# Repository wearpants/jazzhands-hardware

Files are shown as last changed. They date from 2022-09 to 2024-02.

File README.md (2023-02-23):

# Jazz Hands PCBs

A small multi-PCB handheld keyboard for chording style input.

## Main

The main "brains" PCB, which accepts a nice!nano controller.
It exposes connection points with Molex Pico EZMate connectors for 5 `key` PCBs, and a 3-pin Molex Pico EZMate connector for use with the `power-reset` daughterboard PCB.
An untested IMU is also on the main PCB, for future use.

## Key

A small single key PCB with Molex Pico EZMate connector, Kailh hotswap socket, and mounting holes for possible assembly. One mounting hole "wing" is breakaway, as needed.

## Power/Reset

A small daughterboard PCB that contains a reset button and power switch, allowing those two components to be placed elsewhere in a case

# Firmware

See the `wearpants/jazzhands-zmk-config` repo for firmware for the main PCB with ZMK.

# Custom Modifications

It's possible to hack the current `main` PCB to also support a digital hall-effect sensor like the [DRV5023](https://www.ti.com/product/DRV5023) for use in a handheld "switchless design" using magnets only for activation in a glove.

# Production

All three PCBs can be produced by grabbing the generated files from the Actions tab and uploading to JLC, including partial assembly for the `main` PCB using JLC's PCBA service.

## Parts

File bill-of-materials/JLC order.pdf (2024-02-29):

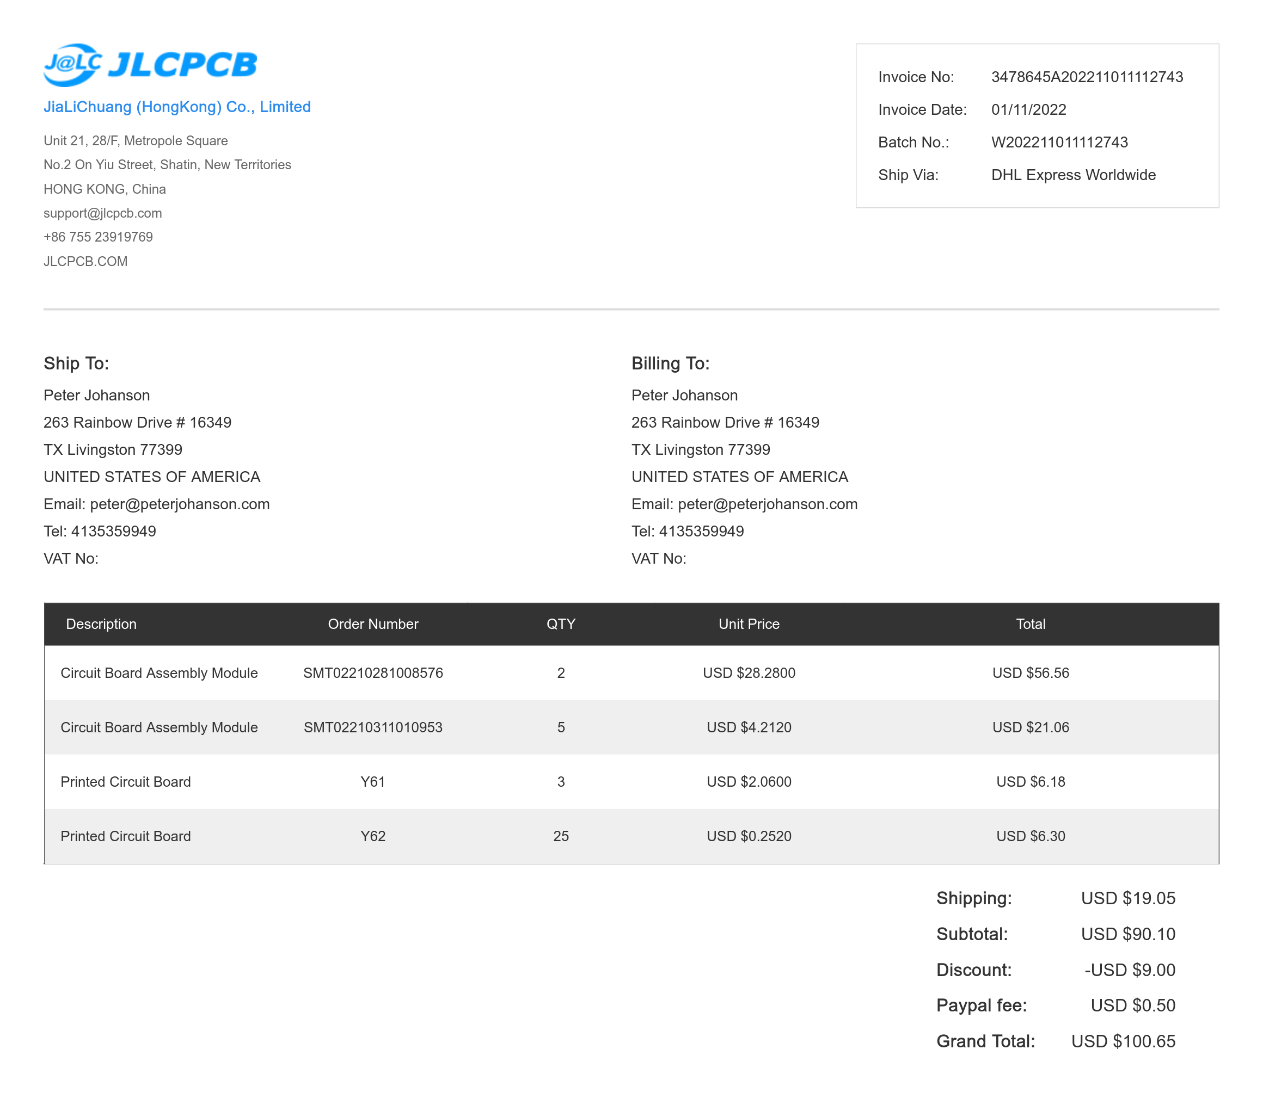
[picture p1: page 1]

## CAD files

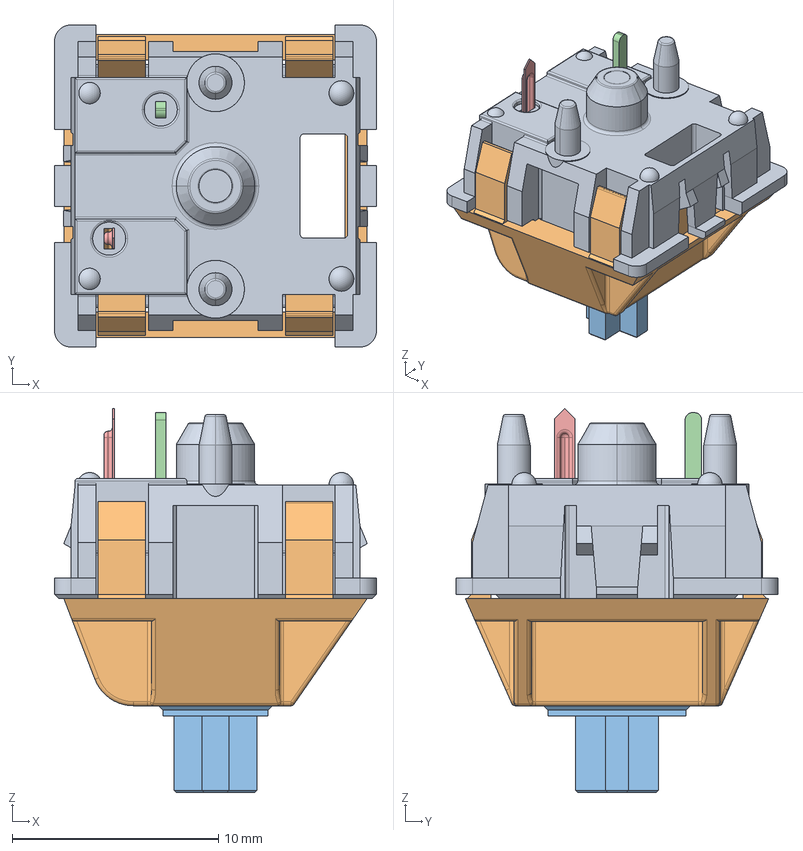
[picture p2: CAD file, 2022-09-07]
key/3d-models/asm_mx_asm_PCB.stp
15.6 x 15.6 x 18.6 mm
MX_DOWN
MX_UP
UP_MX
MX_PIN
MX_SPRING
MX_CLICK

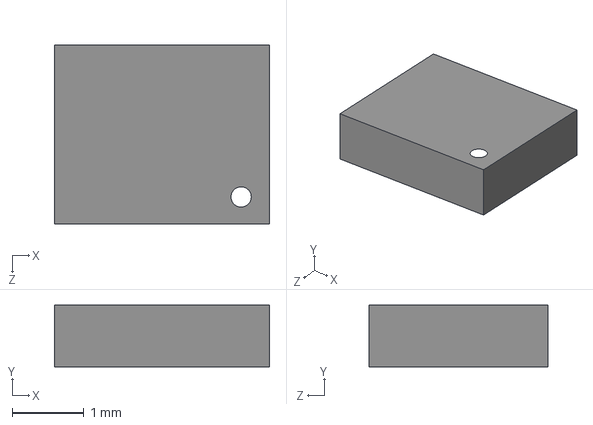
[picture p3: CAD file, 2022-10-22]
main/3d-models/LSM6DSOXTR.step
3.00 x 0.86 x 2.50 mm

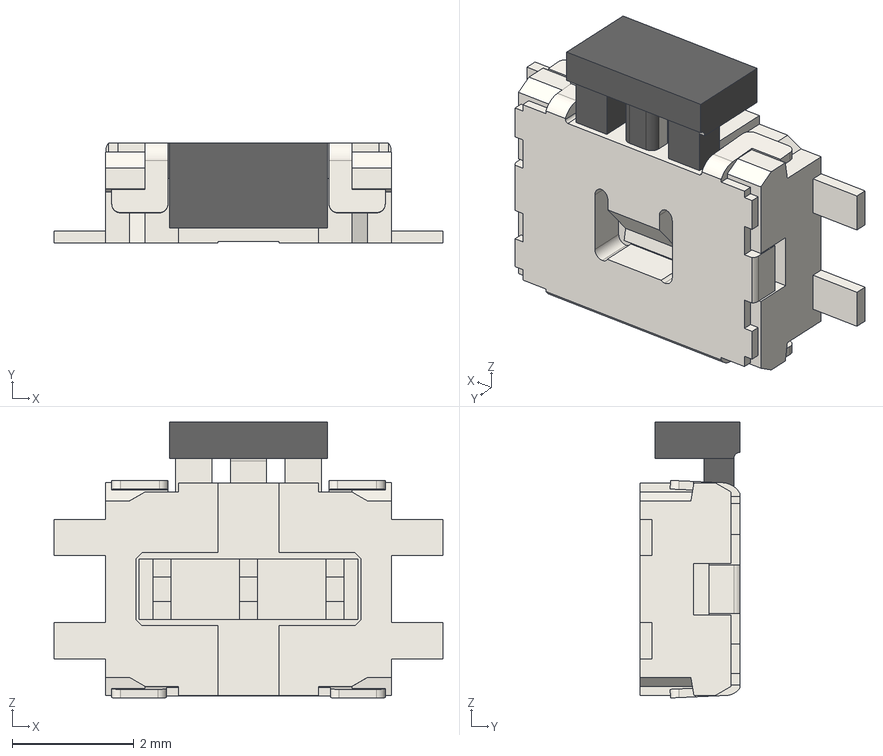
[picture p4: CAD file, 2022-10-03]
power-reset/3d-models/EVQPU-JA-02K.STEP
6.40 x 1.65 x 4.54 mm

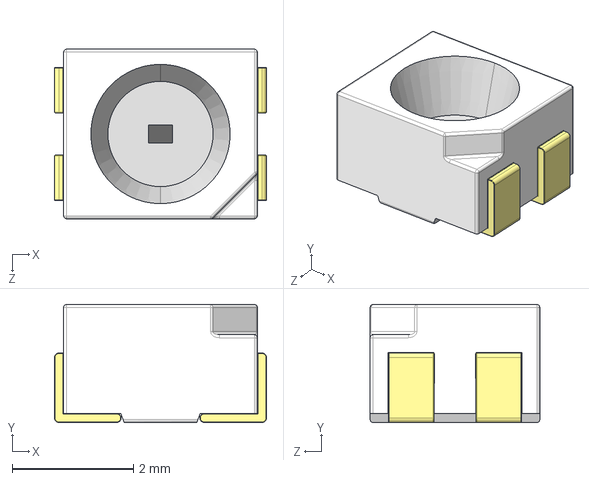
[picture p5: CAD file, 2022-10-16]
main/3d-models/Osram_Led_PLCC4-1.step
3.50 x 1.95 x 2.80 mm

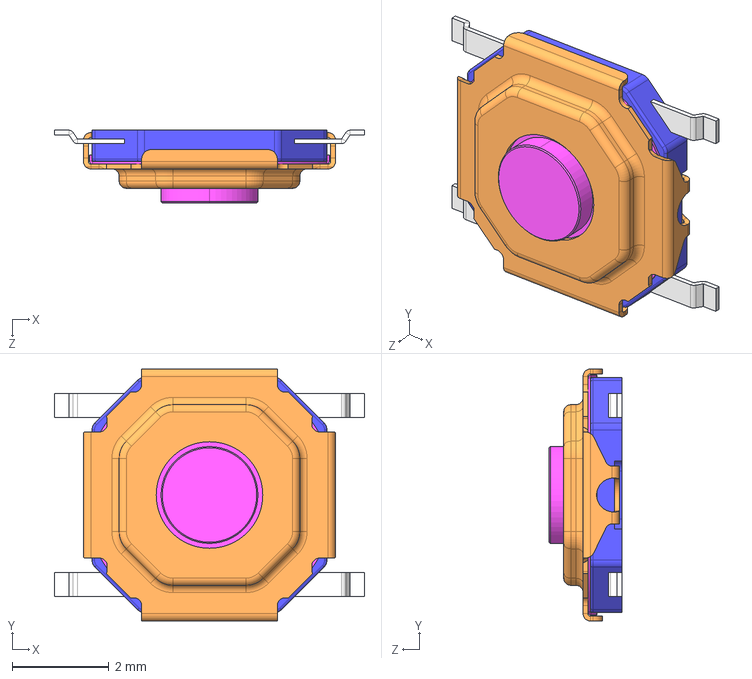
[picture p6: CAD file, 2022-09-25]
main/3d-models/SKQGAF.STEP
6.40 x 5.20 x 1.50 mm

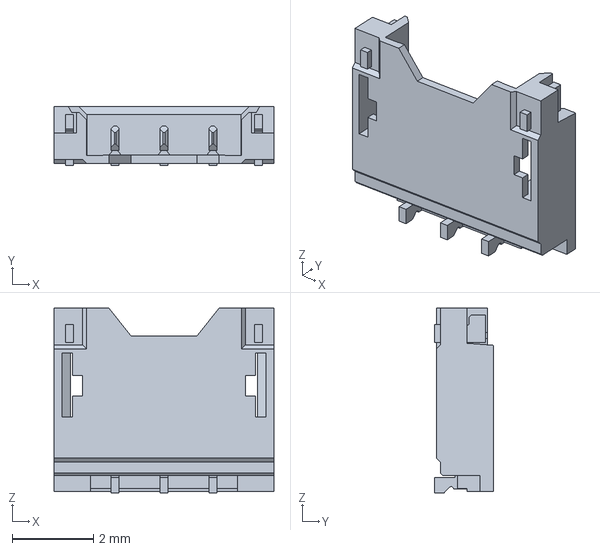
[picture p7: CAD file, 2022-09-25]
power-reset/3d-models/781710003.stp
5.40 x 1.45 x 4.53 mm

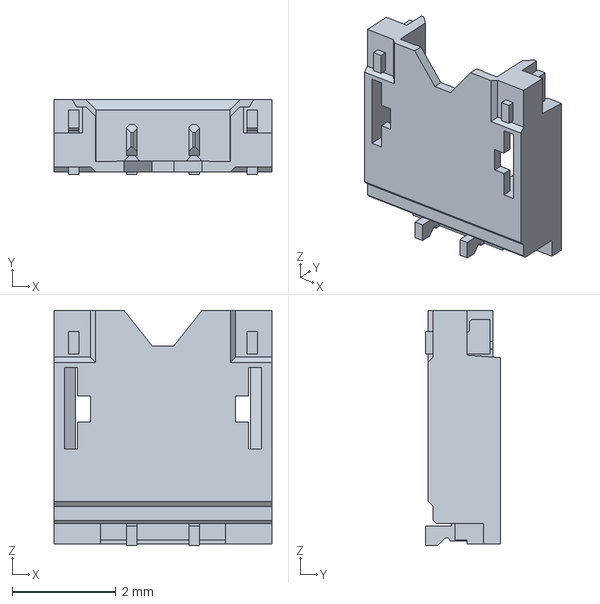
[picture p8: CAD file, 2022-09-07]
main/3d-models/781710002.stp
4.20 x 1.45 x 4.53 mm

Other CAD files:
key/key-sketch.FCStd

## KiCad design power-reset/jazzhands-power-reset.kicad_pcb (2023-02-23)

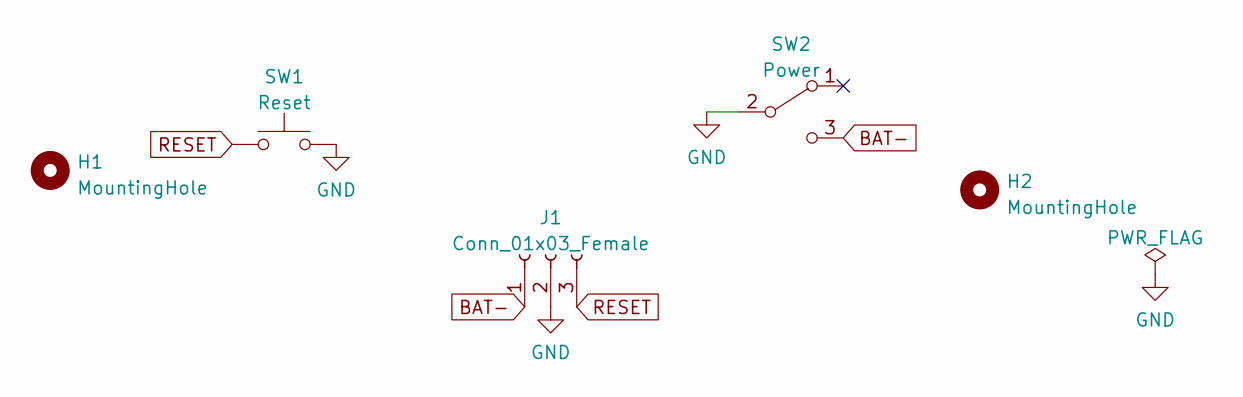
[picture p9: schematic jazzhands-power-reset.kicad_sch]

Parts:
H1, H2: MountingHole; MountingHole_3.2mm_M3_Pad
J1: Conn_01x03_Female; Molex_Pico-EZmate_78171-0003_1x03-1MP_P1.20mm_Vertical
SW1: Reset; Panasonic_EVQPUL_EVQPUC; LCSC Part Number C79174
SW2: Power; SW_SPDT_PCM12; LCSC Part Number C221841

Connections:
BAT-: J1.1, SW2.3 (C)
GND: J1.2, SW1.1, SW2.2 (B)
RESET: J1.3, SW1.2

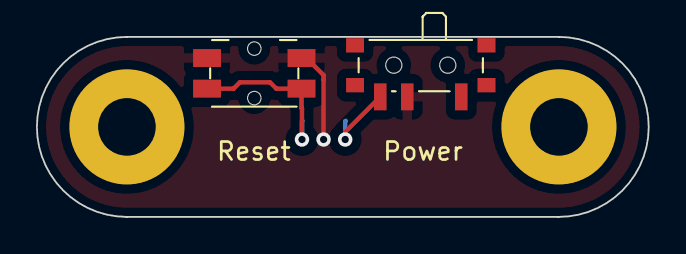
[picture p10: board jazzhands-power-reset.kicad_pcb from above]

Board: 2 copper layers, 34.0 x 10.0 mm, 5 parts (1 on the bottom side), 3 nets.

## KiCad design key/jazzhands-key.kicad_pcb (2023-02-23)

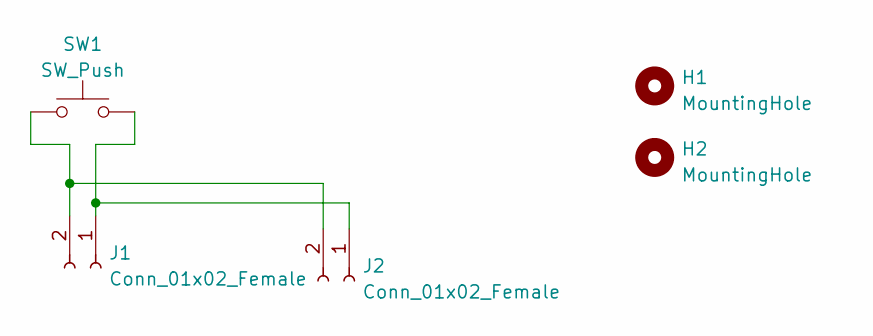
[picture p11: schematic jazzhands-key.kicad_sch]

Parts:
H1, H2: MountingHole; MountingHole_2.2mm_M2_Pad_TopBottom
J1, J2: Conn_01x02_Female; Molex_Pico-EZmate_78171-0002_1x02-1MP_P1.20mm_Vertical
SW1: SW_Push; MXOnly-1U-Hotswap-Antishear

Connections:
unnamed: J1.1, J2.1, SW1.2
unnamed: J1.2, J2.2, SW1.1

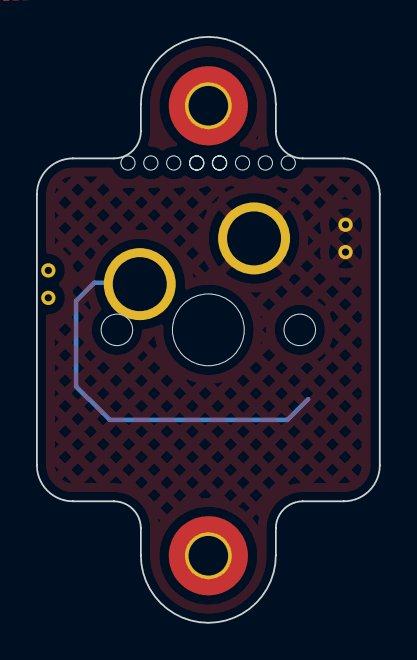
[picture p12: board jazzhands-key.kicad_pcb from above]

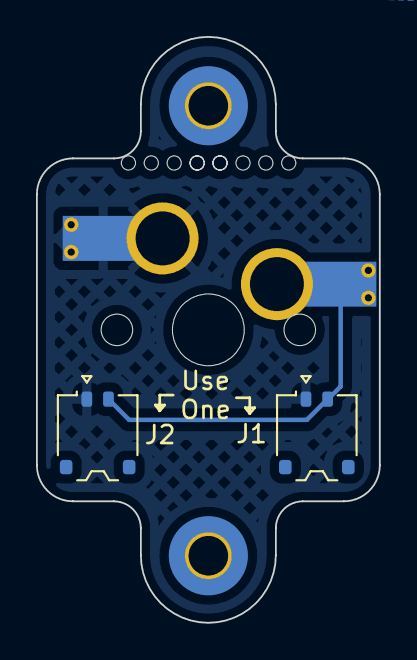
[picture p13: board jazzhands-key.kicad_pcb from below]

Board: 2 copper layers, 19.1 x 32.6 mm, 5 parts (2 on the bottom side), 2 nets.

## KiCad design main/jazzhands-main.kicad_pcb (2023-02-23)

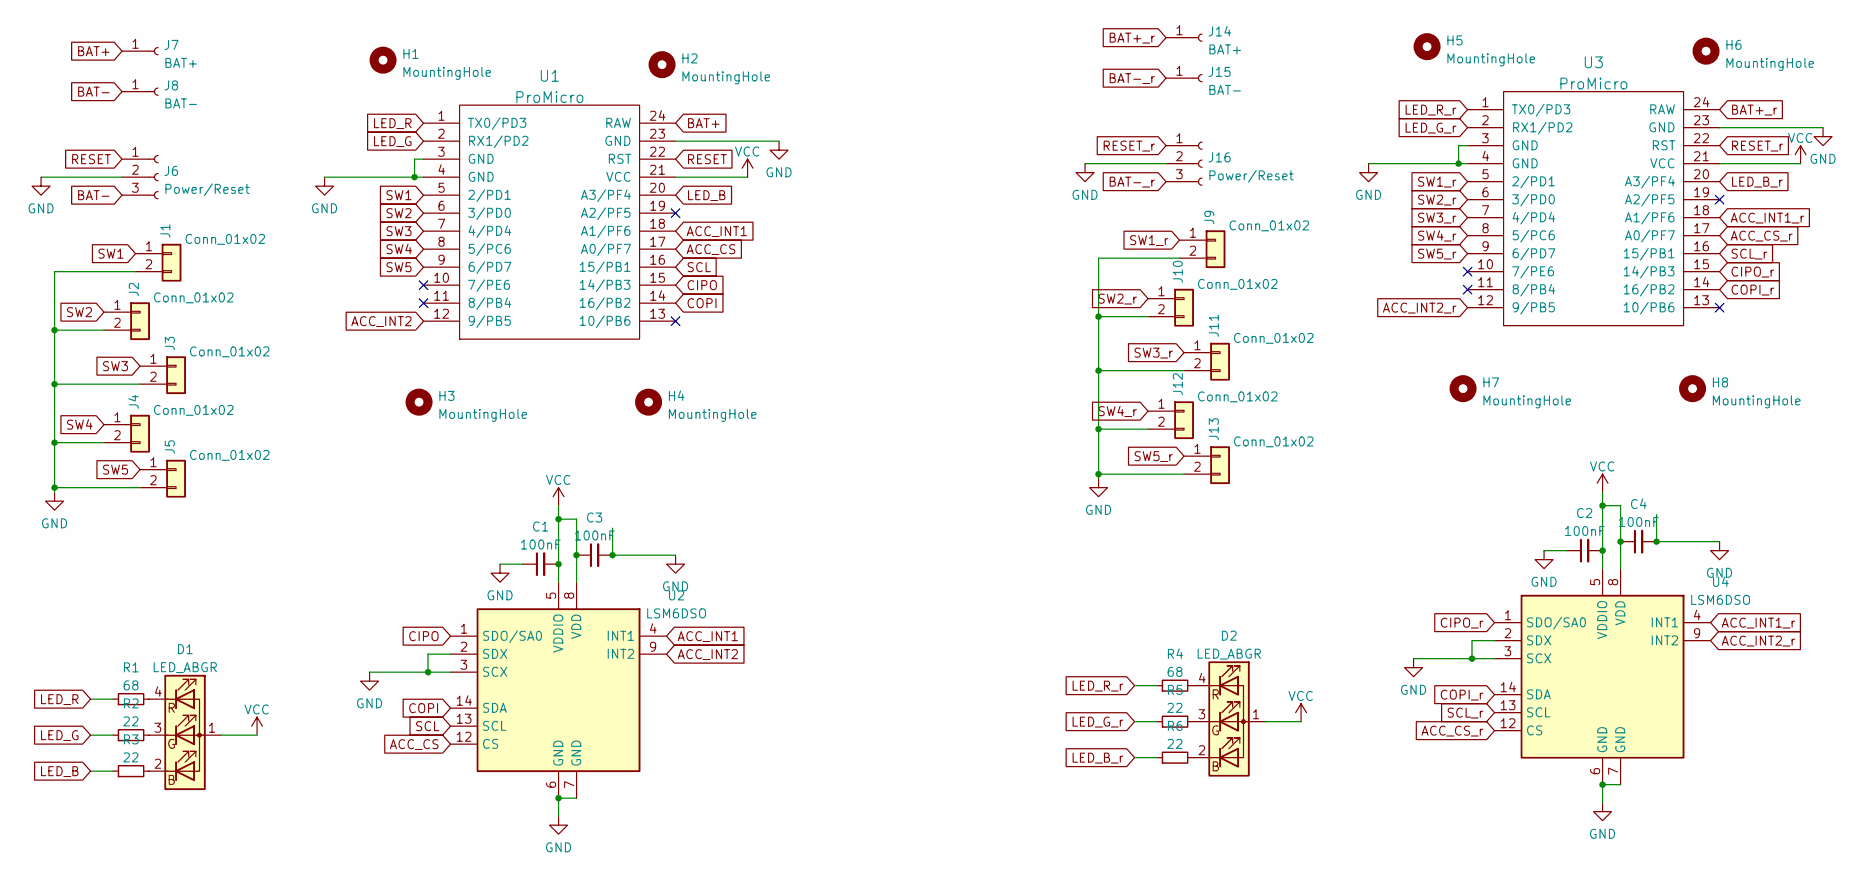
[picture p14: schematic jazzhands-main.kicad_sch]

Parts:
C1, C2, C3, C4: 100nF; C_0603_1608Metric; LCSC Part Number C14663
D1, D2: LED_ABGR; LED_RGB_Wuerth-PLCC4_3.2x2.8mm_150141M173100; LCSC Part Number C409779
H1, H2, H3, H4, H5, H6, H7, H8: MountingHole; MountingHole_2.2mm_M2_Pad
J1, J2, J3, J4, J5, J9, J10, J11, J12, J13: Conn_01x02; Molex_Pico-EZmate_78171-0002_1x02-1MP_P1.20mm_Vertical
J6, J16: Power/Reset; Molex_Pico-EZmate_78171-0003_1x03-1MP_P1.20mm_Vertical
J7, J14: BAT+; PinSocket_1x01_P2.54mm_Vertical
J8, J15: BAT-; PinSocket_1x01_P2.54mm_Vertical
R1, R4: 68; R_0603_1608Metric; LCSC Part Number C27592
R2, R3, R5, R6: 22; R_0603_1608Metric; LCSC Part Number C23345
U1, U3: ProMicro; ArduinoProMicro
U2, U4: LSM6DSO; PQFN50P250X300X86-14N; LCSC Part Number C2655100

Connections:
ACC_CS: U1.17 (A0/PF7), U2.12 (CS)
ACC_CS_r: U3.17 (A0/PF7), U4.12 (CS)
ACC_INT1: U1.18 (A1/PF6), U2.4 (INT1)
ACC_INT1_r: U3.18 (A1/PF6), U4.4 (INT1)
ACC_INT2: U1.12 (9/PB5), U2.9 (INT2)
ACC_INT2_r: U3.12 (9/PB5), U4.9 (INT2)
BAT+: J7.1, U1.24 (RAW)
BAT+_r: J14.1, U3.24 (RAW)
BAT-: J6.3, J8.1
BAT-_r: J15.1, J16.3
CIPO: U1.15 (14/PB3), U2.1 (SDO/SA0)
CIPO_r: U3.15 (14/PB3), U4.1 (SDO/SA0)
COPI: U1.14 (16/PB2), U2.14 (SDA)
COPI_r: U3.14 (16/PB2), U4.14 (SDA)
LED_B: R3.1, U1.20 (A3/PF4)
LED_B_r: R6.1, U3.20 (A3/PF4)
LED_G: R2.1, U1.2 (RX1/PD2)
LED_G_r: R5.1, U3.2 (RX1/PD2)
LED_R: R1.1, U1.1 (TX0/PD3)
LED_R_r: R4.1, U3.1 (TX0/PD3)
unnamed: D1.2 (BK), R3.2
unnamed: D1.3 (GK), R2.2
unnamed: D1.4 (RK), R1.2
unnamed: D2.2 (BK), R6.2
unnamed: D2.3 (GK), R5.2
unnamed: D2.4 (RK), R4.2
RESET: J6.1, U1.22 (RST)
RESET_r: J16.1, U3.22 (RST)
SCL: U1.16 (15/PB1), U2.13 (SCL)
SCL_r: U3.16 (15/PB1), U4.13 (SCL)
SW1: J1.1, U1.5 (2/PD1)
SW1_r: J9.1, U3.5 (2/PD1)
SW2: J2.1, U1.6 (3/PD0)
SW2_r: J10.1, U3.6 (3/PD0)
SW3: J3.1, U1.7 (4/PD4)
SW3_r: J11.1, U3.7 (4/PD4)
SW4: J4.1, U1.8 (5/PC6)
SW4_r: J12.1, U3.8 (5/PC6)
SW5: J5.1, U1.9 (6/PD7)
SW5_r: J13.1, U3.9 (6/PD7)

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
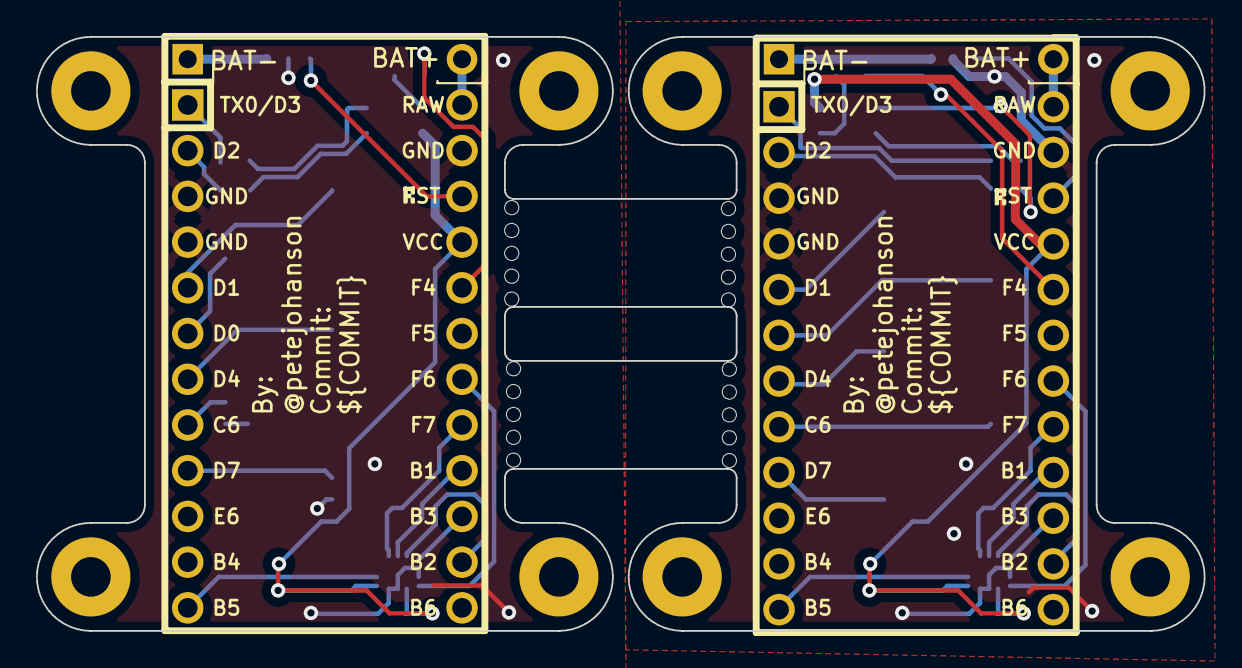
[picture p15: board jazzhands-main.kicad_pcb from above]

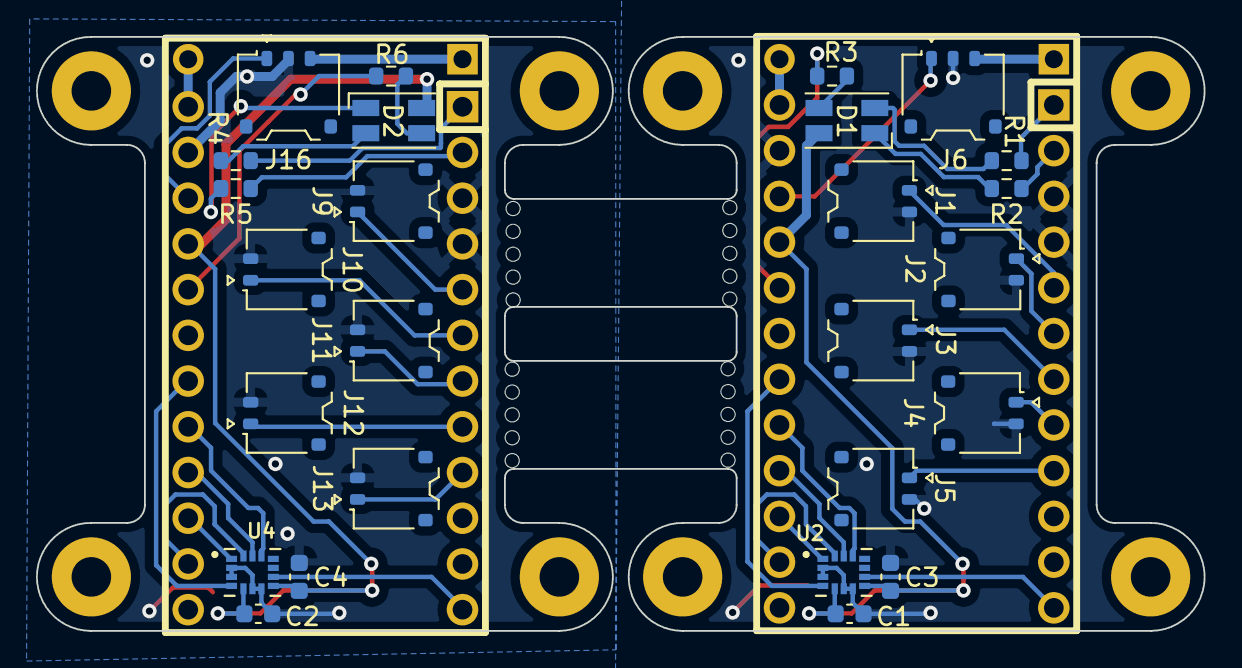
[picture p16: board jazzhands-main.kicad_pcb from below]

Board: 2 copper layers, 64.9 x 33.0 mm, 40 parts (26 on the bottom side), 44 nets.

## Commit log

2022-09-07 Initial individual key PCB.
    * Supports Kailh MX hotswap sockets
    * Molex Pico EZMate connector for direct wire connection.
    * Outline from constrained sketch in FreeCAD.
    [781710002.stp, asetniopy-key.kicad_pcb, asetniopy-key.kicad_sch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]
2022-09-25 Initial main daughterboard PCB.
    [781710002.stp, 781710003.stp, SKQGAF.STEP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]
2022-10-03 Initial power/reset PCB.
    [781710003.stp, EVQPU-JA-02K.STEP, asetniopy-power-reset.kicad_pcb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]
2022-10-03 Minor key PCB tweaks.
    [asetniopy-key.kicad_pcb]
2022-10-06 Assembly zip
2022-10-06 Add LCSC Part numbers for a few parts to test.
    [asetniopy-main.kicad_pcb, asetniopy-main.kicad_sch]
2022-10-06 More parts, rotation/placement fixes.
    [asetniopy-main.kicad_pcb, asetniopy-main.kicad_sch]
2022-10-06 Renders for the other boards.
2022-10-06 Minor placement/silk tweaks.
    [asetniopy-main.kicad_pcb, asetniopy-main.kicad_sch]
2022-10-16 Switch to RGB LED.
    [Osram_Led_PLCC4-1.step, asetniopy-main.kicad_pcb, asetniopy-main.kicad_sch]
2022-10-22 Move to LSM6DSO iNEMO IC.
    [LSM6DSOXTR.step, asetniopy-main.kicad_pcb, asetniopy-main.kicad_sch]
2022-10-23 Left and right boards, joined via mouse bites.
    [asetniopy-main-outline.FCStd, asetniopy-main.kicad_pcb, asetniopy-main.kicad_sch]
2022-10-24 Add mouse bites for key mounting section
    * Move keeb.io lib up for re-use of the submodule.
    * Add second jumper to the key PCB.
    [asetniopy-key.kicad_pcb, asetniopy-key.kicad_sch]
2022-10-28 Add part number for gyro.
    [asetniopy-main.kicad_sch]
2022-10-28 Proper 0603 resistors.
    [asetniopy-main.kicad_sch]
2022-10-28 A few silk label placement fixes.
    [asetniopy-main.kicad_pcb]
2022-10-28 Fix assembly type for sensor.
    [asetniopy-main.kicad_pcb]
2022-10-28 Fix sensor rotation for pick and place.
2022-10-31 Enlarge power/reset enough for JLC assembly.
    [asetniopy-power-reset.kicad_pcb]
2022-10-31 Add LSCS part numbers to power/reset.
    [asetniopy-power-reset.kicad_sch]
2022-10-31 Fix property name typo.
    [asetniopy-power-reset.kicad_sch]
2022-10-31 Fix reset button CPL rotation.
2023-02-23 Rename from asetniopy to jazzhands.
    [jazzhands-key.kicad_pcb, jazzhands-key.kicad_sch, jazzhands-main.kicad_pcb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]
